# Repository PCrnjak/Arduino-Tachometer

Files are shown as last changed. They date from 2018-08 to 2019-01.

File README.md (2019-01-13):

# Arduino-Tachometer

This is open source tachometer project that is focused on making small ,compact and precise tachometer.
In this github repository you will find everything needed to build this , from code to the STL files and building instructions.
There are 2 design versions that use same code but cases are slightly different , but that will be discussed elsewhere in this repository.YouTube [link](https://www.youtube.com/watch?v=HuFqqmQe_AE) of device in action.

tacho gif

## Table of contents

 1. [Intro](#intro)
 2. [Table of contents](#table)
 3. [How to use](#use)
 3. [Bill of materials](#bill)
 4. [Building instructions](#inst)
 5. [Code](#code)
 6. [Troubleshooting](#Trouble)

 ## How to use
 tacho1
 
 There are 2 versions of this tachometer . Only difference is in size and boost converters used.Version that worked for me was [v2.0 STL](https://github.com/PCrnjak/Arduino-Tachometer/tree/master/Tacho%20v2.0%20STL) v1.0 STL didnt work correctly for me because i think i had defective boost convereter . So V2 uses larger boost convereter and V1 uses smaller boost convereter(THAT MIGHT NOT WORK FOR YOU TOO).There is also version with buttons and without buttons.I used version without buttons( they also have no use in code).
 
 tacho tape

 To use this tachometer you will need to have some kind of reflective tape( I used aluminium foil) that will cover about 1-1.5 cm of the
 shaft that will be rotating.Rest of the shaft can be any other colour , but i recommend to make rest of the rotating object black because you will have much less trouble calibrating .After you placed tape on shaft you can check at what distance does sensor trigger .Slowly move side of rotating object with reflective tape closer to the sensor , once bottom led triggers rotate object so that non-reflective side is on sensor , it sould not trigger the sensor .If it does go to Troubleshooting. If it does not trigger you can try to mesure speed of your object.I managed to mesure speeds up to 6000 RPM , but it might be able to mesure higher I just didnt have motors that spin faster.

 ## Bill of materials
 
 | Name   | Link | Comment |
| ------------- | ------------- | ------------- |
| Arduino pro mini  | [link](https://www.ebay.com/itm/Pro-Mini-Enhancement-ATMEGA328P-5V-16MHz-Compatible-to-Arduino-PRO-mini/191679508570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)  |    |
| IR sensor  | [Link](https://www.ebay.com/itm/2Pcs-Reflective-3pin-IR-Infrared-Obstacle-Avoidance-Sensor-Module-for-Arduino/192067056868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)  |  |
| Li ion battery charger   | [Link](https://www.ebay.com/itm/5V-Mini-USB-Charger-Module-for-3-7V-Lithium-Li-ion-18650-Battery-4-2V-Protection/232746845709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)     |       |
| 18650 Li-Ion battery   |     | Got mine from laptop battery      |
| Slide switch   |[Link](https://www.ebay.com/itm/10Pcs-On-Off-SPDT-Vertical-3-Pin-1P2T-Mini-Micro-Vertical-Slide-Switch/391684755384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)     |       |
|15mm M3 screws    |     | 2 pieces     |
|5mm M2 screws    |     |  4 pieces     |
|M3 nuts    |     | 2 pieces      |
| Boost converter V1   |[Link](https://www.ebay.com/itm/1-2-5-10PCS-DC-DC-Boost-Converter-Step-Up-Module-1-5V-to-5V-500mA-for-Arduino/311945927376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)    | This one is used in V1 and might not work      |
| Boost converter V2   |[Link](https://www.ebay.com/itm/DC-3-24V-to-5V-28V-9V-12V-24V-2A-Adjustable-Boost-Step-Up-Converter-Power-Module/112619032791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)     |This is used in V2 and is proven to work       |
| Female header pins   | [Link](https://www.ebay.com/itm/10PCS-40Pin-2-54mm-Single-Row-Straight-Female-Pin-Header-Strip-PBC-Ardunio/180974322541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)    |       |
| SMD push button   | [Link](https://www.ebay.com/itm/100pcs-3X6X2-5mm-Tactile-Push-Button-Switch-Tact-Switch-Micro-Switch-2Pin-SMD-S2/261995936109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)    | OPTIONAL       |
| Perf board   |[Link](https://www.ebay.com/itm/10pcs-New-PCB-Prototype-Perf-Universal-Board-Breadboard-5cm-x-7cm-PCB-Board/292371392551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)    | OPTIONAL       |

You will also need [FTDI USB to TTL Serial Adapter Module](https://www.ebay.com/itm/FT232RL-3-3V-5-5V-FTDI-USB-to-TTL-Serial-Adapter-Module-for-Arduino-Mini-Port/381374421597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) to program your arduino pro mini.

 ## Building instructions
 
 Building instructions can be found on instructables page of this [project](https://www.instructables.com/id/Arduino-Tachometer/).
 
## Code
[Speed test](https://github.com/PCrnjak/Arduino-Tachometer/blob/master/speed_test.ino) is code I used to comfirm that my tachometer was mesuring right speed.More about how it works and how to implement the code can be found in the file.[RPM tacho display](https://github.com/PCrnjak/Arduino-Tachometer/blob/master/rpm_tacho_display.ino) is code used on tachometer to mesure speed.

## Troubleshooting
Firstly test if your sensor works correctly.One of its leds should trigger at specific distance that you can tweek by blue pot on board.
If it does not trigger at all or stays triggered all the time you maybe have defective sensor.
If your sensor on tachometer triggers on both reflective tape and rest of the object try to make rest of the object black. You can print black circle on your printer or 3D print costum part like i did.

## TRIGGERED
tacho on

## NOT TRIGGERED
tacho off

Other problems i noticed:
- When mesuring speed i noticed that changes in light can faulty trigger sensor and cause "spike" of wrong speed.
  - If sensor is too far from mesured object it will start to shoot random speed values.
    - Quick change in speed can cause "spike" in displayed speed

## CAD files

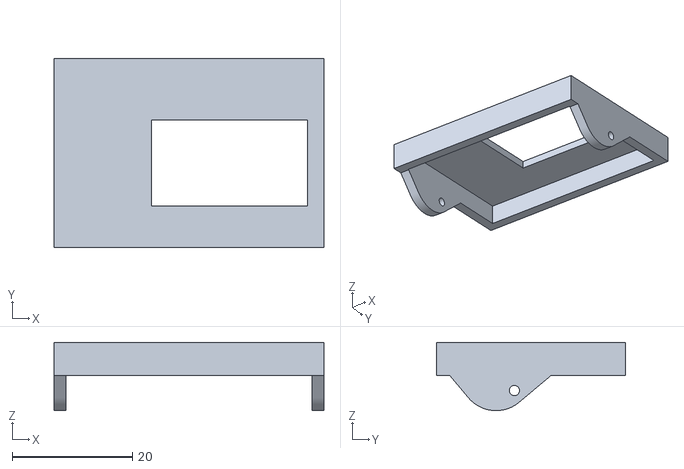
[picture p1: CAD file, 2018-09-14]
lid without holes.STL
44.8 x 31.4 x 11.3

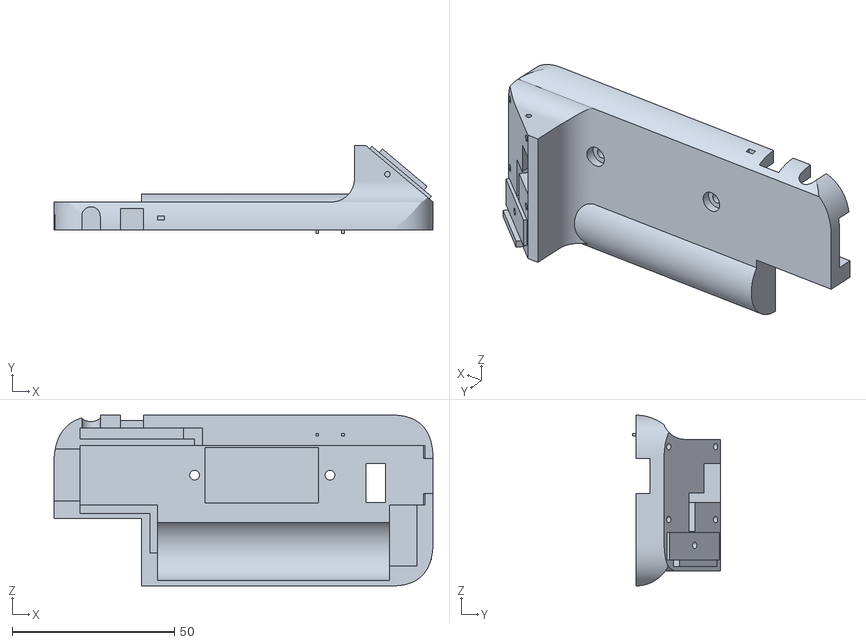
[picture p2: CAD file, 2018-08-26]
Tacho v2.0 STL/Top v2.0.STL
117.0 x 27.1 x 52.8

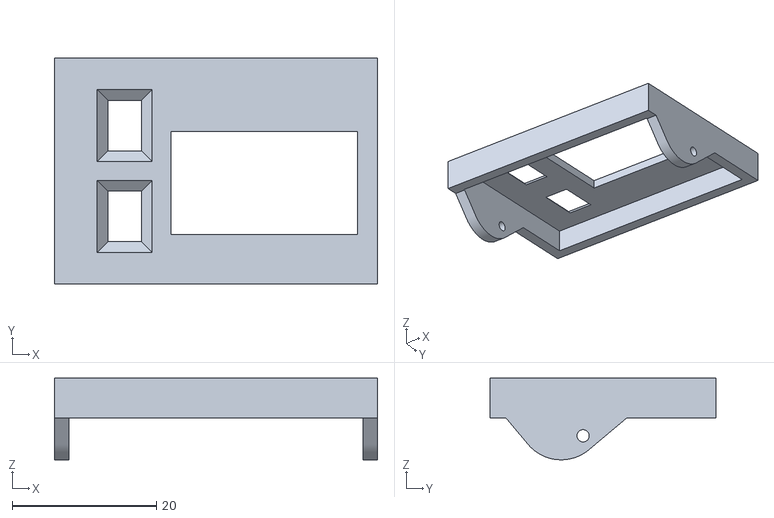
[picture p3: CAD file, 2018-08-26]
Tacho v2.0 STL/LID.STL
44.8 x 31.4 x 11.3

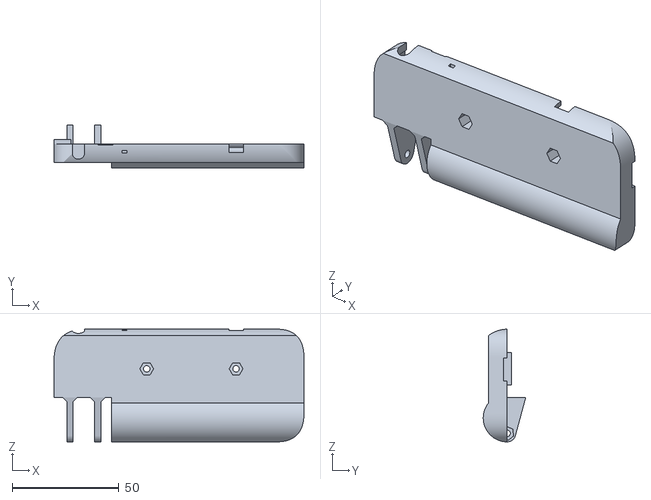
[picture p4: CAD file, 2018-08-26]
Tacho v2.0 STL/bottom v2.0.STL
117.0 x 19.9 x 52.8

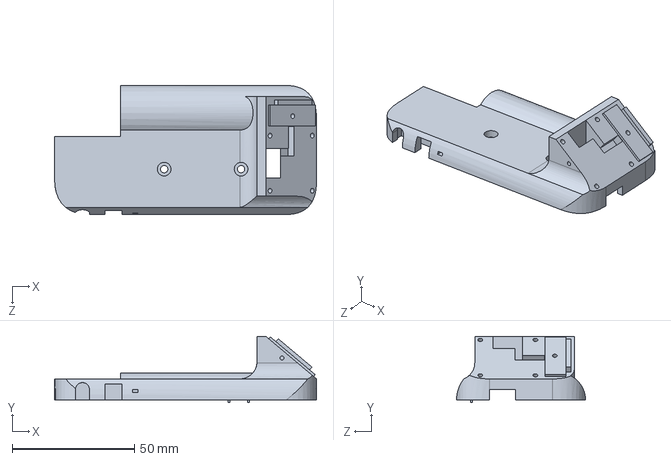
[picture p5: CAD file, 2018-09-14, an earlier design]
Tacho v1.0 STL/top v1.0.SLDPRT
107.0 x 27.1 x 52.8 mm

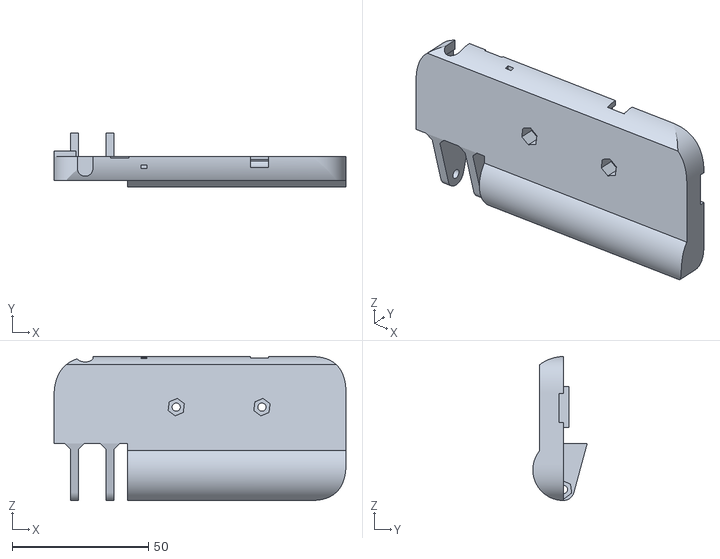
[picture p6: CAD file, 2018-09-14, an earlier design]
Tacho v1.0 STL/bottom v1.0.STL
107.0 x 19.9 x 52.8

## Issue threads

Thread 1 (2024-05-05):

sharing of your Arduino Tachometer project

aeonSolutions, 2024-05-05:
hi @deepsyx
great work!  👍👍👍👍👍

i'm sharing your project on my own "Open Hardware Electronics for the Volvo P2 platform"
[https://github.com/aeonSolutions/AeonLabs-AI-Volvo-MKII-Open-Hardware/wiki/Programming-the-Instruments-Cluster](https://github.com/aeonSolutions/AeonLabs-AI-Volvo-MKII-Open-Hardware/wiki/Programming-the-Instruments-Cluster)

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

PCrnjak, 2024-05-05:
Cool, Thank you!

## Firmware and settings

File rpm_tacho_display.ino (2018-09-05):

#include <SPI.h>
#include <Wire.h>
#include <Adafruit_GFX.h>
#include <Adafruit_SSD1306.h>

#define OLED_RESET 4
Adafruit_SSD1306 display(OLED_RESET);


unsigned int rpm;
unsigned long prevmillis=0;
volatile byte state;
unsigned int duration;
unsigned long prevTime = 0; 
#define updateTime 350

void setup() {
attachInterrupt(1,interrupt,RISING); 
 Serial.begin(9600);
 display.begin(SSD1306_SWITCHCAPVCC, 0x3C);
 display.clearDisplay();
}

void loop() {
 
if(state==true){
  detachInterrupt(1);
  duration = ( millis() - prevmillis );
  prevmillis = millis();
  
 
  if(millis() - prevTime >= updateTime) {
     prevTime = millis(); 
      ///Serial.print("\t RPM:  ");
     // Serial.println(rpm);
     rpm = (60000/duration)/1;   
     display.clearDisplay();
     display.setTextSize(2);
     display.setTextColor(WHITE);
     display.setCursor(3,9);
     display.println("RPM:");
     display.setCursor(60,9);
     display.println(rpm);  
     display.display();   
  }
  state=false;
  attachInterrupt(1,interrupt,RISING); 
  
  }
}


void interrupt(){
 state=true;

}

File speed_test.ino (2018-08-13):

/*
 /////////////////////////////STEPPER SPEED TEST//////////////////////
 
 This sketch is used as test for my 3d printed tachometer , but it can also be used for anyone
 that wants to control speed of stepper with press of a button.It works like this:
 when you start your arduino and have everything hooked up , your motor should spin at 93 RPM if
 you used parametars i used for microstepping and pulse widht. RPM is calculated by this formula:
(60/(200*(1/microstepping)*2*pulse_widht*0.000001)).You should see those 93 RPM on your LCD display.
After every button press pulse widht is reduced by 20 microseconds, and new speed is calculated and
displayed on LCD.

 The circuit:
 * LCD RS pin to digital pin 12
 * LCD Enable pin to digital pin 11
 * LCD D4 pin to digital pin 5
 * LCD D5 pin to digital pin 4
 * LCD D6 pin to digital pin 8
 * LCD D7 pin to digital pin 9
 * LCD R/W pin to ground
 * 10K resistor:
 * ends to +5V and ground
 * wiper to LCD VO pin (pin 3)
 * 
 * Our switch will be used with pull-down resistor like this:
 * one end of switch goes to the 220 ohm resistor and D2 on arduino
 * another end of switch goes to 5V ,and unconnected lead of resistor goes to the GND.
 * 
 * There are alot of different stepper drivers but they all have STEP/PULS pin and DIR pin
 * STEP/PULS pin of stepper driver goes to the D6 on arduino
 * DIR pin of stepper driver goes to the D7 on arduino


Written by Petar Crnjak https://github.com/PCrnjak
*/

// include the library code:
#include <LiquidCrystal.h>
// initialize the library by associating any needed LCD interface pin
// with the arduino pin number it is connected to
const int rs = 12, en = 11, d4 = 5, d5 = 4, d6 = 8, d7 = 9;
LiquidCrystal lcd(rs, en, d4, d5, d6, d7);

//Define what kind of microstepping you are using ,default is 0.5 ( or half stepping )
// 1/4 stepping would be 0.25 ,1/8 would be 0.125 and so on ....
#define microstepping 0.5

// Pulse_widht that will be decreased by pressing button
volatile int pulse_widht=1000; /// 1000 microseconds
byte state=LOW;  
int RPM=0;

unsigned long previousMillis=0;

volatile byte control_state=LOW;


const int stepPin = 6; // this pin goes to the PULS pin on stepper driver
const int dirPin = 7;  // Direction pin on stepper controller

void setup() {
//Define pins that go in stepper driver as outputs
pinMode(stepPin,OUTPUT); 
pinMode(dirPin,OUTPUT);

//Define LCD's number of colums and rows
lcd.begin(16, 2);
lcd.print("RPM:"); // Print out rpm 
digitalWrite(dirPin,HIGH); // Here you can change direction by changing HIGH to LOW
attachInterrupt(0,increment,RISING); // Attaching interrupt to pin 2 of arduino
/////Here we precalculate RPM for default pulse_widht of 1000 microseconds
//// Because we want to display RPM even if we never pressed button to increment it
 lcd.setCursor(0, 1);   
 RPM=(60/(200*(1/microstepping)*2*pulse_widht*0.000001));   ///(60/(0.0008*pulse_widht));
 lcd.print(RPM);

}

void loop(){
  unsigned long currentMillis=micros();
 ////// state is used to prevent triggering of this if statement twice in row 
 ///// same goes for second one , this secures perfect square wave form
  if(currentMillis-previousMillis>=pulse_widht and state==LOW){
    previousMillis=currentMillis;
    digitalWrite(stepPin,HIGH);
    state=HIGH;
    
  }
  if(currentMillis-previousMillis>=(pulse_widht) and state==HIGH) {
    previousMillis=currentMillis;
    digitalWrite(stepPin,LOW);
    state=LOW;
    
  }
  ///// This if statement triggers every time button is pressed and it prints new RPM value
  if(control_state==HIGH){
    lcd.setCursor(0, 1);   
    RPM=(60/(200*(1/microstepping)*2*pulse_widht*0.000001)); 
    lcd.print(RPM);
    control_state=LOW;
  }

}

void increment(){
  static unsigned long last_interrupt_time = 0;
  unsigned long interrupt_time = millis();
   // If interrupts come faster than 250ms, assume it's a bounce and ignore
  if (interrupt_time - last_interrupt_time > 250) {
          //////// Here we decease pulse_widht wich in turn increases RPM
          pulse_widht=pulse_widht - 20;
          control_state=HIGH;
    }else{
         control_state=LOW;     
   }   
last_interrupt_time = interrupt_time;
}

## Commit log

2018-08-13 Code for testing tachometer
    Code is used to test accuracy of tachometer.By setting different pulse widths using push button, we change RPM of stepper motor that is then being displayed on LCD screen or on serial monitor . Then 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
2018-08-26 Version 2 of STL files
    version 1 and 2 look the same but version 2 is longer for 1 cm and has some internal , invisible changes because of different boost converter module inside.
    [LID.STL, Top v2.0.STL, bottom v2.0.STL]
2018-09-09 Added bill of materials
2018-09-14 Version one STL files
    [bottom v1.0.STL, top v1.0.SLDPRT]
2018-09-14 lid without holes for push buttons
    [lid without holes.STL]
